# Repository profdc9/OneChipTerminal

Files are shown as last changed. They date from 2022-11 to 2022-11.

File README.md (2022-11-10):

# One Chip Terminal
The One Chip Terminal by Daniel L. Marks.

This project is to use a really cheap board, the Bluepill (STM32F103C8T6 or CS32F103C8T6) to implement a VT100/ANSI terminal for a television set. 
It has NTSC video output which is compatible with many televisions, and uses a PS/2 keyboard input.  The project uses USART1 and implements hardware flow control.
Because it uses the Bluepill project board, it can be implemented with no soldering and incorporated easily into any project.  There is a PCB that may
be used if one desires to add a line-level serial port to it.

There are two compiled firmware files, one for the STM32F103C8T6 and one for the CS32F103C8T6.  Getting one of the clone boards to work is an
exercise in masochism, but it's what is largely available now.

It uses the (somewhat antiquated now) Arduino STM32 libraries:

https://github.com/rogerclarkmelbourne/Arduino_STM32

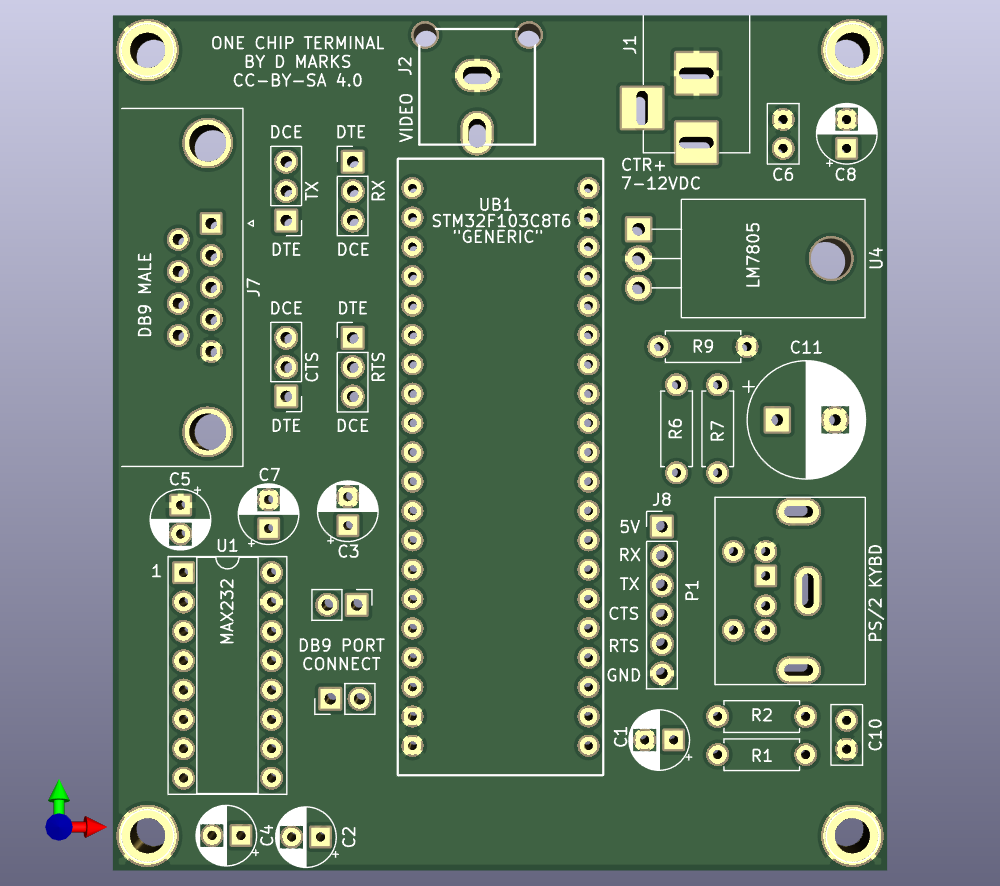
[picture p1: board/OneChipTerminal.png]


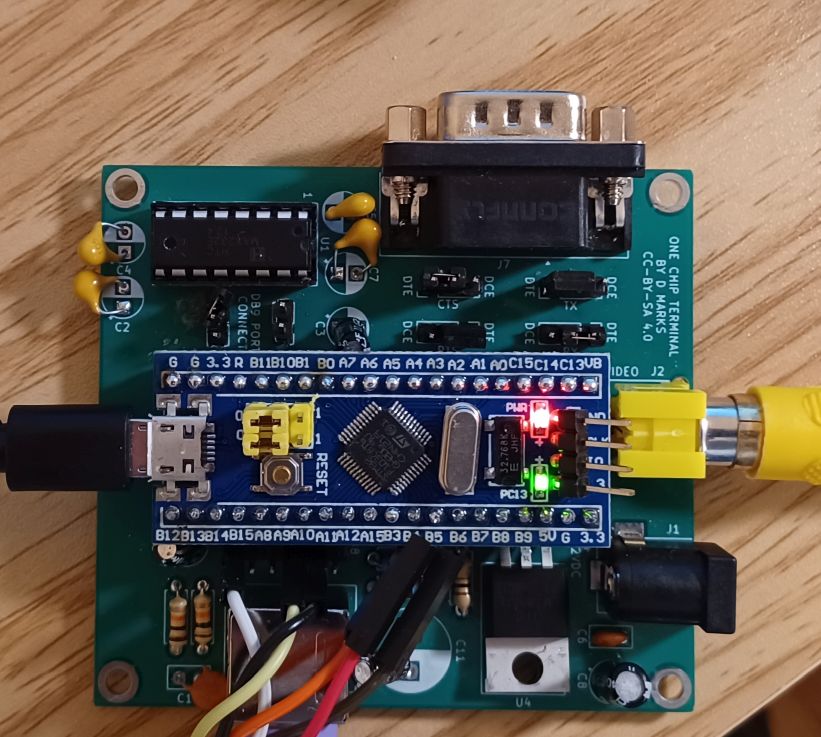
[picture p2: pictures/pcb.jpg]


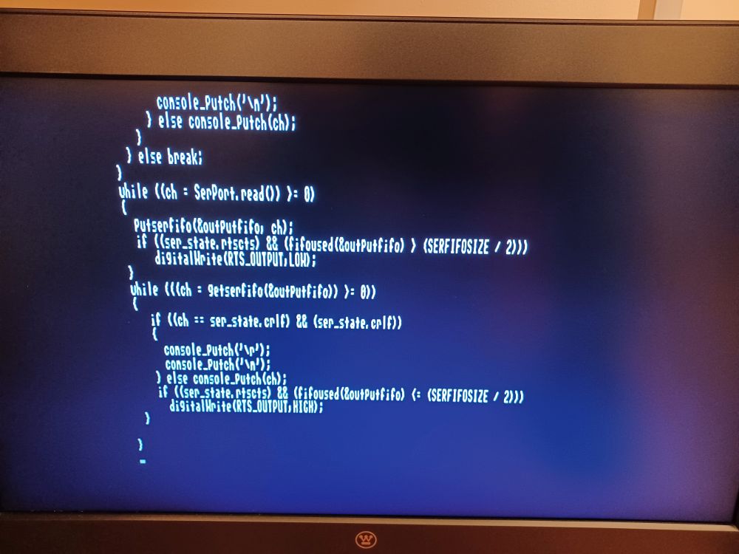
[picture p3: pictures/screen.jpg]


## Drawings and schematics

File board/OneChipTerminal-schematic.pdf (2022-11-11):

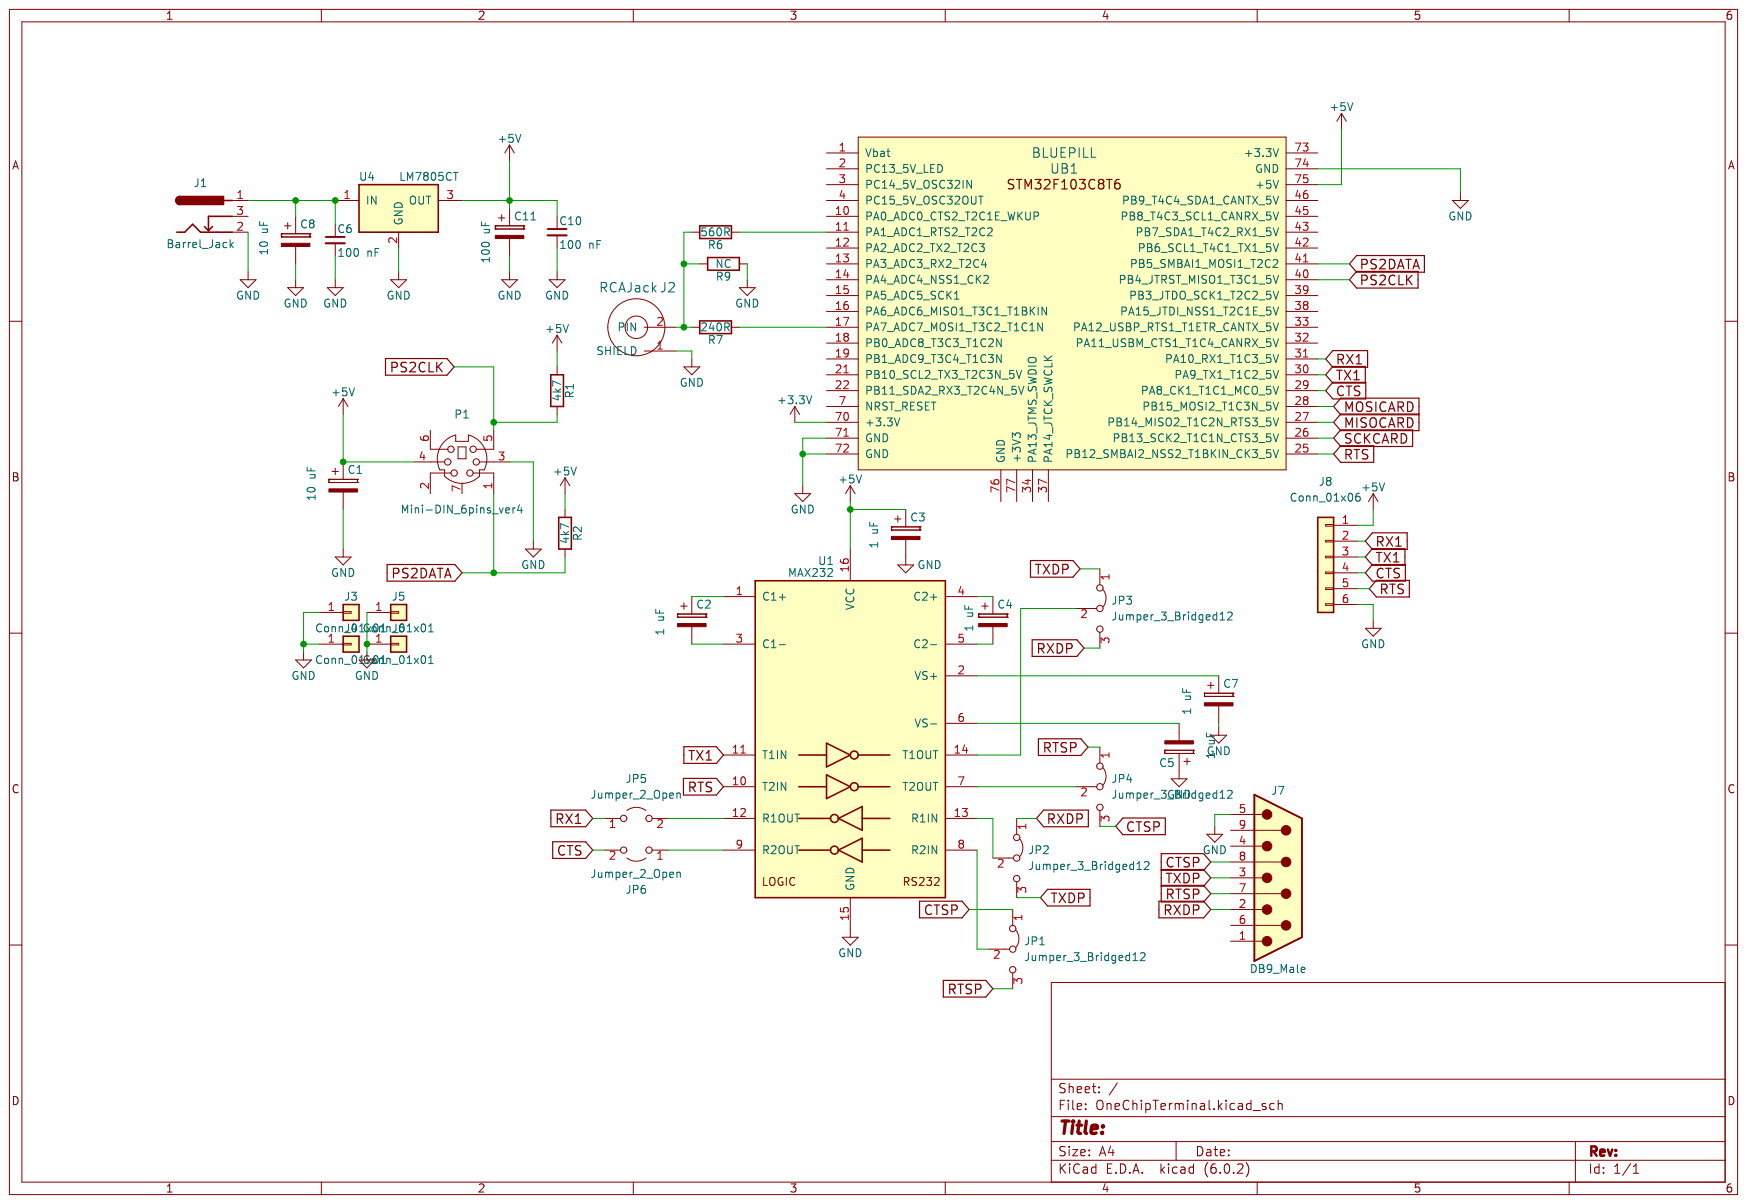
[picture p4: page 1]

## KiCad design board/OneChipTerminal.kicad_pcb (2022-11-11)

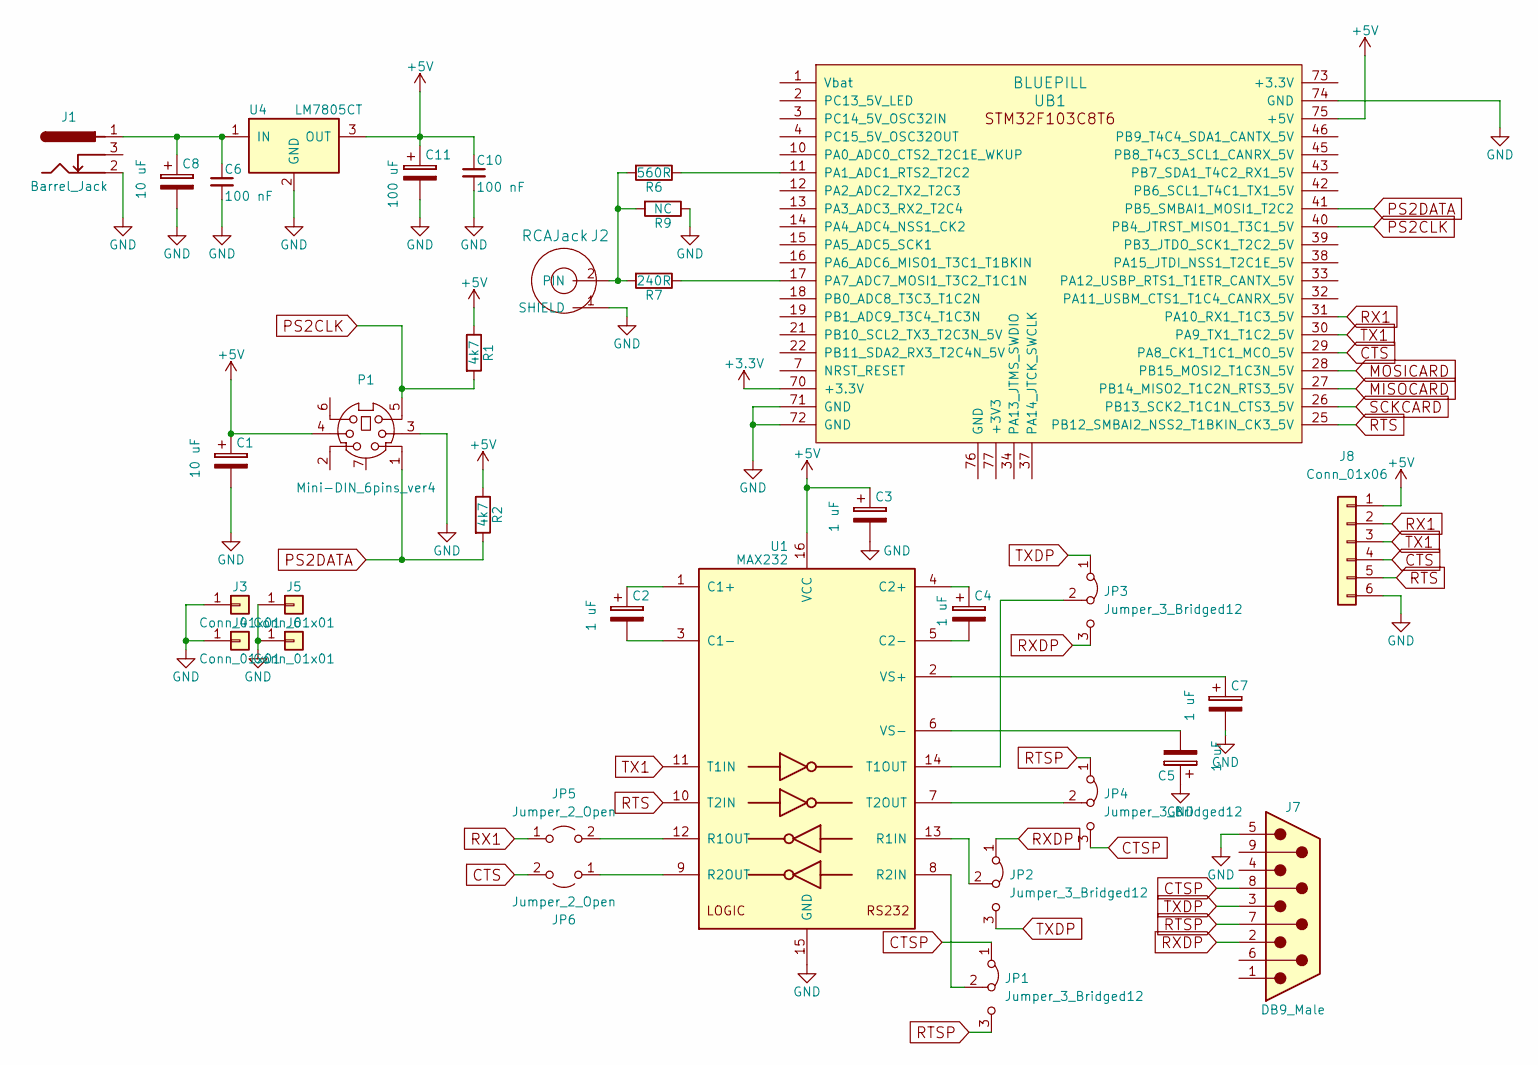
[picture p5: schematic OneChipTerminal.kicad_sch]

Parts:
C1, C8: 10 uF; CP_Radial_D5.0mm_P2.50mm
C2, C3, C4, C5, C7: 1 uF; CP_Radial_D5.0mm_P2.50mm
C6, C10: 100 nF; C_Disc_D5.0mm_W2.5mm_P2.50mm
C11: 100 uF; CP_Radial_D10.0mm_P5.00mm
J1: Barrel_Jack; BARREL_JACK
J2: RCAJack; RCAConnectorCommon
J3, J4, J5, J6: Conn_01x01; 1pin
J7: DB9_Male; DSUB-9_Male_Horizontal_P2.77x2.84mm_EdgePinOffset4.94mm_Hou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
J8: Conn_01x06; PinHeader_1x06_P2.54mm_Vertical
JP1, JP2, JP3, JP4: Jumper_3_Bridged12; PinHeader_1x03_P2.54mm_Vertical
JP5, JP6: Jumper_2_Open; PinHeader_1x02_P2.54mm_Vertical
P1: Mini-DIN_6pins_ver4; Connector_Mini-DIN_Female_6Pin_2rows
R1, R2: 4k7; R_Axial_DIN0207_L6.3mm_D2.5mm_P7.62mm_Horizontal
R6: 560R; R_Axial_DIN0207_L6.3mm_D2.5mm_P7.62mm_Horizontal
R7: 240R; R_Axial_DIN0207_L6.3mm_D2.5mm_P7.62mm_Horizontal
R9: NC; R_Axial_DIN0207_L6.3mm_D2.5mm_P7.62mm_Horizontal
U1: MAX232; DIP-16_W7.62mm_Socket
U4: LM7805CT; TO-220-3_Horizontal_TabDown
UB1: BLUEPILL

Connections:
+3V3: UB1.70 (+3.3V)
+5V: C1.1, C3.1, C10.1, C11.1, J8.1, P1.4, R1.1, R2.1, U1.16 (VCC), U4.3 (OUT), UB1.75 (+5V)
CTS: J8.4, JP6.2 (B), UB1.29 (PA8_CK1_T1C1_MCO_5V)
CTSP: J7.8, JP1.1 (A), JP4.3 (B)
GND: C1.2, C3.2, C5.1, C6.2, C7.2, C8.2, C10.2, C11.2, J1.2, J2.1 (SHIELD), J3.1, J4.1, J5.1, J6.1, J7.5, J8.6, P1.3, R9.1, U1.15 (GND), U4.2 (GND), UB1.71 (GND), UB1.72 (GND), UB1.74 (GND)
MISOCARD: UB1.27 (PB14_MISO2_T1C2N_RTS3_5V)
MOSICARD: UB1.28 (PB15_MOSI2_T1C3N_5V)
unnamed: C2.1, U1.1 (C1+)
unnamed: C2.2, U1.3 (C1-)
unnamed: C4.1, U1.4 (C2+)
unnamed: C4.2, U1.5 (C2-)
unnamed: C5.2, U1.6 (VS-)
unnamed: C6.1, C8.1, J1.1, U4.1 (IN)
unnamed: C7.1, U1.2 (VS+)
unnamed: J2.2 (PIN), R6.2, R7.2, R9.2
unnamed: JP1.2 (C), U1.8 (R2IN)
unnamed: JP2.2 (C), U1.13 (R1IN)
unnamed: JP3.2 (C), U1.14 (T1OUT)
unnamed: JP4.2 (C), U1.7 (T2OUT)
unnamed: JP5.2 (B), U1.12 (R1OUT)
unnamed: JP6.1 (A), U1.9 (R2OUT)
unnamed: R6.1, UB1.11 (PA1_ADC1_RTS2_T2C2)
unnamed: R7.1, UB1.17 (PA7_ADC7_MOSI1_T3C2_T1C1N)
PS2CLK: P1.5, R1.2, UB1.40 (PB4_JTRST_MISO1_T3C1_5V)
PS2DATA: P1.1, R2.2, UB1.41 (PB5_SMBAI1_MOSI1_T2C2)
RTS: J8.5, U1.10 (T2IN), UB1.25 (PB12_SMBAI2_NSS2_T1BKIN_CK3_5V)
RTSP: J7.7, JP1.3 (B), JP4.1 (A)
RX1: J8.2, JP5.1 (A), UB1.31 (PA10_RX1_T1C3_5V)
RXDP: J7.2, JP2.1 (A), JP3.3 (B)
SCKCARD: UB1.26 (PB13_SCK2_T1C1N_CTS3_5V)
TX1: J8.3, U1.11 (T1IN), UB1.30 (PA9_TX1_T1C2_5V)
TXDP: J7.3, JP2.3 (B), JP3.1 (A)

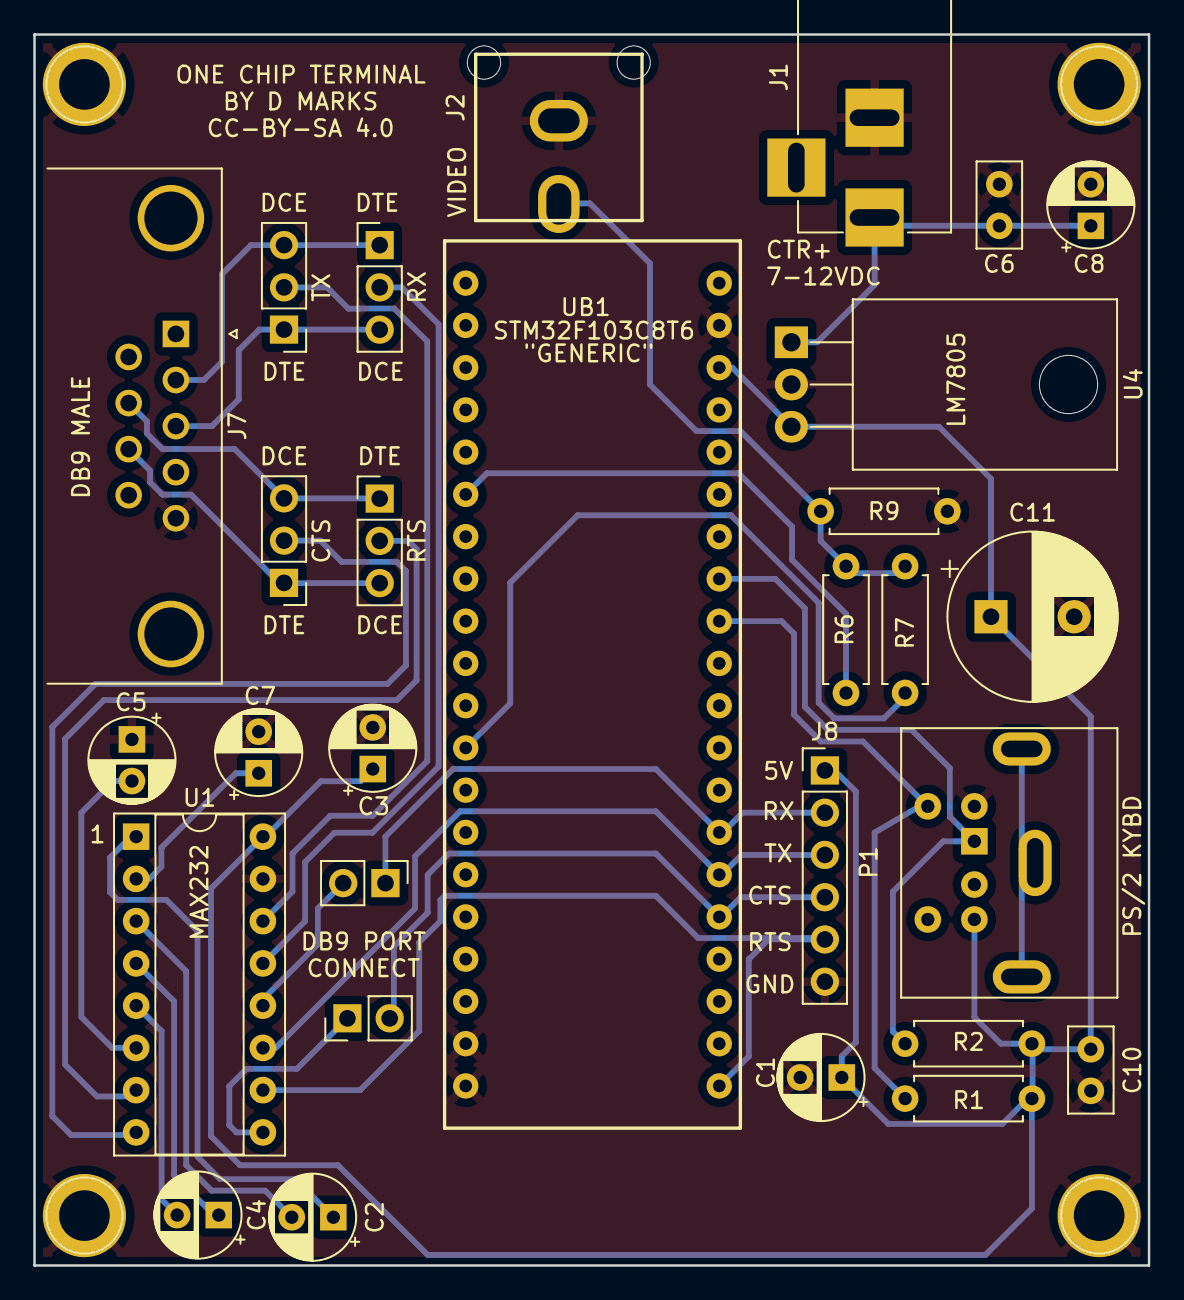
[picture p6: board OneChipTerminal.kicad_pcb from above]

Board: 2 copper layers, 67.0 x 74.0 mm, 33 parts (0 on the bottom side), 28 nets.

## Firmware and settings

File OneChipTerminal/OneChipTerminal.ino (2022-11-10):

#include <Arduino.h>
#include <malloc.h>
#include <SPI.h>
#include <TNTSChar.h>
#include <TNTSCAnsi.h>
#include <PS2Keyboard.h>

#include <libmaple/libmaple.h>
#include <libmaple/gpio.h>
#include <libmaple/timer.h>
#include <libmaple/usart.h>

#include "consoleio.h"
#include "debugmsg.h"
#include "mini-printf.h"
#include "editor.h"
#include "flashstruct.h"

#define RTS_OUTPUT PB12
#define CTS_INPUT PA8

#ifdef SERIAL_USB
#define SerPort Serial1
#else
#define SerPort Serial
#endif

extern PS2Keyboard kbd;
extern TNTSChar_class TNTSChar;

#define MAGIC_DEFAULT 0xA901BEEF

#define SERFIFOSIZE 64

struct serfifo
{
  unsigned char buf[SERFIFOSIZE];
  int fifohead;
  int fifotail;
};

struct serfifo inputfifo;
struct serfifo outputfifo;

static void initserfifo(struct serfifo *fifo)
{
  fifo->fifohead = fifo->fifotail = 0;
}


static int fifoused(struct serfifo *fifo)
{
  if (fifo->fifotail > fifo->fifohead)
      return (SERFIFOSIZE + fifo->fifohead - fifo->fifotail);
  else
      return (fifo->fifohead - fifo->fifotail); 
}

static int getserfifo(struct serfifo *fifo)
{ 
  int ch;
  int newpos;
  if (fifo->fifotail == fifo->fifohead)
    return -1;
  ch = fifo->buf[fifo->fifotail];
  newpos = fifo->fifotail+1;
  if (newpos >= SERFIFOSIZE) newpos = 0;
  fifo->fifotail = newpos;
  return ch;
}

static void putserfifo(struct serfifo *fifo, int ch)
{
  int newpos = fifo->fifohead + 1;
  if (newpos >= SERFIFOSIZE) newpos = 0; 
  if (newpos == fifo->fifotail)
    return;
  fifo->buf[fifo->fifohead] = ch;
  fifo->fifohead = newpos;
}

const char intro[] =
  "One Chip Terminal by D.L. Marks\r\n"
  "zLib license for software, CC-BY-SA 4.0 for hardware\r\n"
  "\r\n\r\nPress ALT-H for help\r\n\r\n";

typedef struct _serial_state
{
  uint32_t magic;
  uint32_t baud;
  uint8_t stopbits;
  uint8_t parity;
  uint8_t localecho;
  uint8_t rtscts;
  uint8_t crlf;
} serial_state;

serial_state ser_state;

#define CONFIGURATION_STORAGE_ADDRESS 0x0800F800u

void configuration_read_storage(void)
{
  void *vp[1];
  int b[1];

  vp[0] = (void *)&ser_state;
  b[0] = sizeof(ser_state);
  readflashstruct((void *)CONFIGURATION_STORAGE_ADDRESS, 1, vp, b);
}

void configuration_write_storage(void)
{
  void *vp[1];
  int b[1];

  vp[0] = (void *)&ser_state;
  b[0] = sizeof(ser_state);
  writeflashstruct((void *)CONFIGURATION_STORAGE_ADDRESS, 1, vp, b);
}

void setup_serial_port(struct _serial_state *ser_state)
{
  uint32_t parity = (ser_state->parity == 'E') || (ser_state->parity == 'O');
  usart_set_baud_rate(USART1, USART_USE_PCLK, ser_state->baud);
  USART1->regs->CR1  = (USART1->regs->CR1 & 0B1110000111111111) | (parity << 10) | ((uint32_t)(ser_state->parity == 'O') << 9);
  USART1->regs->CR2  = (USART1->regs->CR2 & 0B1100111111111111) | ((uint32_t)(ser_state->stopbits == 2) << 13);
  initserfifo(&inputfifo);
  initserfifo(&outputfifo);
}

void setup() {
  configuration_read_storage();
  if (ser_state.magic != MAGIC_DEFAULT)
  {
    ser_state.magic = MAGIC_DEFAULT;
    ser_state.baud = 19200;
    ser_state.stopbits = 1;
    ser_state.parity = 'N';
    ser_state.localecho = 0;
    ser_state.rtscts = 0;
    ser_state.crlf = 0;
  }
  SerPort.begin(19200);
  pinMode(PC13, OUTPUT);
  pinMode(CTS_INPUT,INPUT_PULLUP);
  pinMode(RTS_OUTPUT,OUTPUT);
  digitalWrite(RTS_OUTPUT,HIGH);
  setup_serial_port(&ser_state);
  nvic_irq_set_priority(NVIC_USART1,1);
  console_init();
  console_puts(intro);
}

extern "C" {
void flicker(void)
{
  digitalWrite(PC13,!digitalRead(PC13));
}
}

void write_message(uint8_t row, uint8_t col, const char *c)
{
  uint16_t cols = TNTSChar.cols();
  uint8_t *screendata = TNTSChar.screendata();
  uint8_t *ch = screendata + (cols * row) + col;
  while (*c != 0) *ch++ = *c++;
}

void do_set_baud_rate()
{
  int ch, baud = -1;
  write_message(0,0,"Baud Rate: 0=300,1=1200,2=2400,3=4800,4=9600,5=19200");
  write_message(1,11,"6=38400,7=57600,8=115200,9=230400");
  while ((ch=console_inchar()) < 0);
  switch (ch)
  {
    case '0': baud = 300; break;
    case '1': baud = 1200; break;
    case '2': baud = 2400; break;
    case '3': baud = 4800; break;
    case '4': baud = 9600; break;
    case '5': baud = 19200; break;
    case '6': baud = 38400; break;
    case '7': baud = 57600; break;
    case '8': baud = 115200; break;
    case '9': baud = 230400; break;
  }
  if (baud >= 0)
  {
    char s[20];
    write_message(2,0,"Baud rate set to ");
    myltoa(s, baud);
    write_message(2,18, s);
    ser_state.baud = baud;
    setup_serial_port(&ser_state);
  } else
    write_message(2,0,"Baud rate not selected");
  delay(1000); 
}

#define CLEAR_ROWS 6

void write_pause_message(const char *c)
{
  write_message(0,0,c);
  delay(1000);
}

void do_set_no_parity(void)
{
  ser_state.parity = 'N';
  setup_serial_port(&ser_state);
  write_pause_message("No parity set");
}

void do_set_even_parity(void)
{
  ser_state.parity = 'E';
  setup_serial_port(&ser_state);
  write_pause_message("Even parity set");
}

void do_set_odd_parity(void)
{
  ser_state.parity = 'O';
  setup_serial_port(&ser_state);
  write_pause_message("Odd parity set");
}

void do_set_one_stop_bit(void)
{
  ser_state.stopbits = 1;
  setup_serial_port(&ser_state);
  write_pause_message("One stop bit set");
}

void do_set_two_stop_bits(void)
{
  ser_state.stopbits = 2;
  setup_serial_port(&ser_state);
  write_pause_message("Two stop bits set");
}

void do_local_echo(void)
{
  ser_state.localecho = !ser_state.localecho;
  write_pause_message(ser_state.localecho ? "Local echo on" : "Local echo off");  
}

void do_flow_control(void)
{
  ser_state.rtscts = !ser_state.rtscts;
  write_pause_message(ser_state.rtscts ? "Hardware flow control on" : "Hardware flow control off");  
}

void do_crlf(uint8_t ch, const char *c)
{
  ser_state.crlf = ch;
  write_message(0,16,c);
  write_pause_message("CRLF sequence: ");
}

void do_write_storage(void)
{
  configuration_write_storage();
  write_pause_message("Configuration written to flash");  
}

void do_show_help(void)
{
  write_message(0,0,"Alt-H Help, Alt-B Baud Rate, Alt-N No Parity, Alt-E Even Parity");
  write_message(1,0,"Alt-O Odd Parity, Alt-1 One Stop Bit, Alt-2 Two Stop Bits,");
  write_message(2,0,"Alt-L Toggle Local Echo, Alt-F Toggle Hardware Flow Control,");
  write_message(3,0,"Alt-J LF is CRLF, Alt-M CR is CRLF, Alt-R none is CRLF,");
  write_message(4,0,"Alt-W Write Configuration To Flash");  
  while (console_inchar() < 0);
}

void do_altkey(void)
{
  uint16_t rows = TNTSChar.rows();
  uint16_t cols = TNTSChar.cols();
  uint16_t tchars = rows*cols;
  uint8_t *screendata = TNTSChar.screendata(), *save_screen;
  volatile uint16_t *xpos, *ypos;
  uint16_t save_xpos, save_ypos;

  TNTSChar.get_cursor_ptr(&xpos,&ypos);
  if ((save_screen = (uint8_t *)malloc(tchars)) == NULL) return;
  memcpy(save_screen, screendata, tchars);
  save_xpos = *xpos;
  save_ypos = *ypos;

  while (kbd.altkey())
  {
    int ch = console_inchar();
    if (ch >= 0)
    {
      memset(screendata,' ', cols*(CLEAR_ROWS-1));
      memset(screendata+(cols*(CLEAR_ROWS-1)),' ' | 0x80,cols);  
      ch = toupper(ch);
      switch (ch)
      {
         case 'H':  do_show_help();
                    break;
         case 'B' : do_set_baud_rate();
                    break;
         case 'N':  do_set_no_parity();
                    break;
         case 'E':  do_set_even_parity();
                    break;
         case 'O':  do_set_odd_parity();
                    break;
         case '1':  do_set_one_stop_bit();
                    break;
         case '2':  do_set_two_stop_bits();
                    break;
         case 'L':  do_local_echo();
                    break;
         case 'F':  do_flow_control();
                    break;
         case 'J':  do_crlf('\n', "LF");
                    break;
         case 'M':  do_crlf('\r', "CR");
                    break;
         case 'R':  do_crlf('\000', "none");
                    break;
         case 'W':  do_write_storage();
                    break;
      }
    }
  }
  
  *xpos = save_xpos;
  *ypos = save_ypos;
  memcpy(screendata, save_screen, tchars);
  free(save_screen);
}


void loop()
{
  int ch;
  if (kbd.altkey())
    do_altkey();
  while ((ch = console_inchar()) >= 0)
    putserfifo(&inputfifo, ch);
  while ((!ser_state.rtscts) || (digitalRead(CTS_INPUT)))
  {
    if ((ch = getserfifo(&inputfifo)) >= 0)
    {
      Serial.write(ch);
      if (ser_state.localecho) 
      {
        if ((ch == ser_state.crlf) && (ser_state.crlf))
        {
          console_putch('\r');
          console_putch('\n');
        } else console_putch(ch);
      }
    } else break;
  }
  while ((ch = SerPort.read()) >= 0)
  {
    putserfifo(&outputfifo, ch);
    if ((ser_state.rtscts) && (fifoused(&outputfifo) > (SERFIFOSIZE / 2)))
       digitalWrite(RTS_OUTPUT,LOW);
  }
  while (((ch = getserfifo(&outputfifo)) >= 0))
  {
     if ((ch == ser_state.crlf) && (ser_state.crlf))
     {
       console_putch('\r');
       console_putch('\n');
     } else console_putch(ch);
     if ((ser_state.rtscts) && (fifoused(&outputfifo) <= (SERFIFOSIZE / 2)))
       digitalWrite(RTS_OUTPUT,HIGH);
  }

}
